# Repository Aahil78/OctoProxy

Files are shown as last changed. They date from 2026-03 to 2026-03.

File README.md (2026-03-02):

# OctoProxy

OctoProxy is a raspberry pi based OctoPrint server for the Bambu Lab A1, it acts as a proxy for region locked and LAN Only mode printers to have remote monitoring and access. It also has a Tailscale VPN server to trick Bambu Studio to think you are on  your LAN when you arent, this will allow you to send prints from Bambu Studio to any LAN Only printer from anywhere in the world. You can also use it as a printago fuse or simplyprint server.

Features:
  - Runs OctoPrint allowing you to send prints from anywhere.
  - Uses a Raspberry Pi 4 as the SBC, allowing for upgrades like sensors, lights, software upgrades, and more.
  - WS2812B/SK6812 3 Pin connector for custom lights.
  - Has a CSI Camera, allowing better timelapses and better video streaming footage. We all know the A1 Camera is..... special.
  - GPIO Pins broken out for upgrades.

## Images

### PCB:



### Case:





(Top has magnets embedded)

### Schematic:



## BOM:

| Item: | Quantity: | Price: | Link: | Total Cost: |
|---|---|---|---|---|
| Raspberry Pi 4 (Already have it) | 1 | $0 | N/A | |
| Raspberry Pi 4 Camera | 1 | $23.08 | Camera | |
| PCB | 1 | $15.78 | | |
| Raspberry Pi Fan | 1 | $4.35  | Fan | |
| Standoffs & Screws | 1 kit | $10 | Screws and standoffs | |
| 3 Pin Female Header | 3 | $2.50  | 3 Pin Header | |
| 4 Pin Female Header | 2 | $2.72  | 4 Pin Header | |
| 7 Pin Female Header | 1 | $3.10  | 7 Pin Header | |
| 6 Pin Female Header | 2 | $2.95  | 6 Pin Header | |
| 2 Pin Male Header | 1 | $1.00  | 2 Pin Header | |
| 1 Pin Header | 1 | $1 | 1 Pin Header | |
| 330ohm Resistor | 1 | $1.47  | Resistor | |
| 40Pin SMT Connector | 1 | $4.77  | SMT Connector | |
| WS2812B LED Strip | 1 | $6.46  | LED Strip | |
| | | | | 79.18 (Will pay extra myself) |

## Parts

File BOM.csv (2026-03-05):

Item: | Quantity: | Price: | Link: | Total Cost:
Raspberry Pi 4 (Already have it) | 1 | $0 | N/A
Raspberry Pi 4 Camera | 1 | $23.08 | https://a.aliexpress.com/_c3WMvg8r
PCB | 1 | $15.78 (Buying myself)
Raspberry Pi Fan | 1 | $4.35 | https://a.aliexpress.com/_c4KBPFfh
Standoffs & Screws | 1 kit | $10 | https://a.aliexpress.com/_c3n6VUOF
3 Pin Female Header | 3 | $2.50 | 3https://a.aliexpress.com/_c3jsRT47
4 Pin Female Header | 2 | $2.72 | https://a.aliexpress.com/_c3jsRT47
7 Pin Female Header | 1 | $3.10 | https://a.aliexpress.com/_c3jsRT47
6 Pin Female Header | 2 | $2.95 | https://a.aliexpress.com/_c3jsRT47
2 Pin Male Header | 1 | $1.00 | https://a.aliexpress.com/_c3YBvwLN
1 Pin Header | 1 | $1 | https://a.aliexpress.com/_c3YBvwLN
330ohm Resistor | 1 | $1.47 | https://a.aliexpress.com/_c44BS1eP
40Pin SMT Connector | 1 | $4.77 | https://a.aliexpress.com/_c3YsGuH1
WS2812B LED Strip | 1 | $6.46 | https://a.aliexpress.com/_c3SKBgij
3.5inch DSI LCD | 1 | $30.94 | https://a.aliexpress.com/_c3eojfjv
 |  |  |  | $93.98 (Will pay extra myself)

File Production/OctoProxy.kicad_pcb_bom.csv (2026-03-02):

Designator | Quantity | Value | Footprint | Package | MPN | DNP | Mount_Type | Description
J1 | 1 | GPIO | Raspberry_Pi_Shield_Bottom_Entry_No_Mounting_Holes |  |  |  | tht
J10, J3 | 2 | Conn_01x04_Pin | Harwin_M20-89004xx_1x04_P2.54mm_Horizontal |  |  |  | smt
J11, J2, J6 | 3 | Conn_01x03_Pin | Harwin_M20-89003xx_1x03_P2.54mm_Horizontal |  |  |  | smt
J4 | 1 | Conn_01x07_Pin | Harwin_M20-89007xx_1x07_P2.54mm_Horizontal |  |  |  | smt
J5 | 1 | Conn_01x02_Pin | PinHeader_1x02_P2.54mm_Horizontal |  |  |  | tht | Generic connector, single row, 01x02, script generated
J7, J8 | 2 | Conn_01x06_Pin | Harwin_M20-89006xx_1x06_P2.54mm_Horizontal |  |  |  | smt
J9 | 1 | Conn_01x01_Pin | PinHeader_1x01_P2.54mm_Horizontal |  |  |  | tht | Generic connector, single row, 01x01, script generated
R3 | 1 | 330ohm | R_Axial_DIN0207_L6.3mm_D2.5mm_P10.16mm_Horizontal |  |  |  | tht | 330Ω, 1/4W Resistor

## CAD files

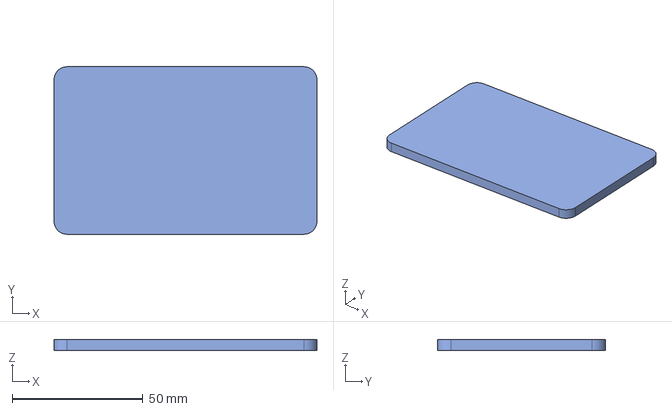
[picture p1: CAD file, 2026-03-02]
CAD/Top.step
100.6 x 64.1 x 4.20 mm

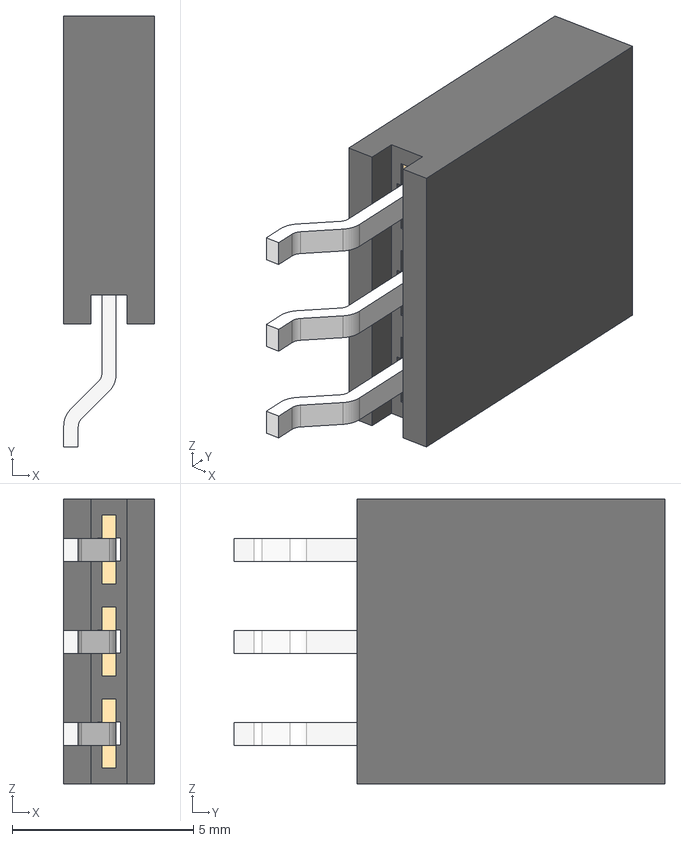
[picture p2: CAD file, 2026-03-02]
src/3D Models/3pin-right-angled-2.54mm.stp
2.50 x 11.9 x 7.87 mm

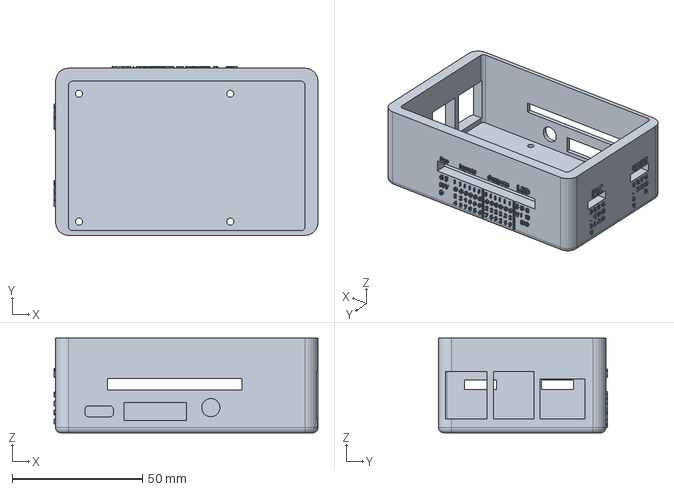
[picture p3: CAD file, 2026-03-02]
CAD/Base.step
101.2 x 64.7 x 36.3 mm

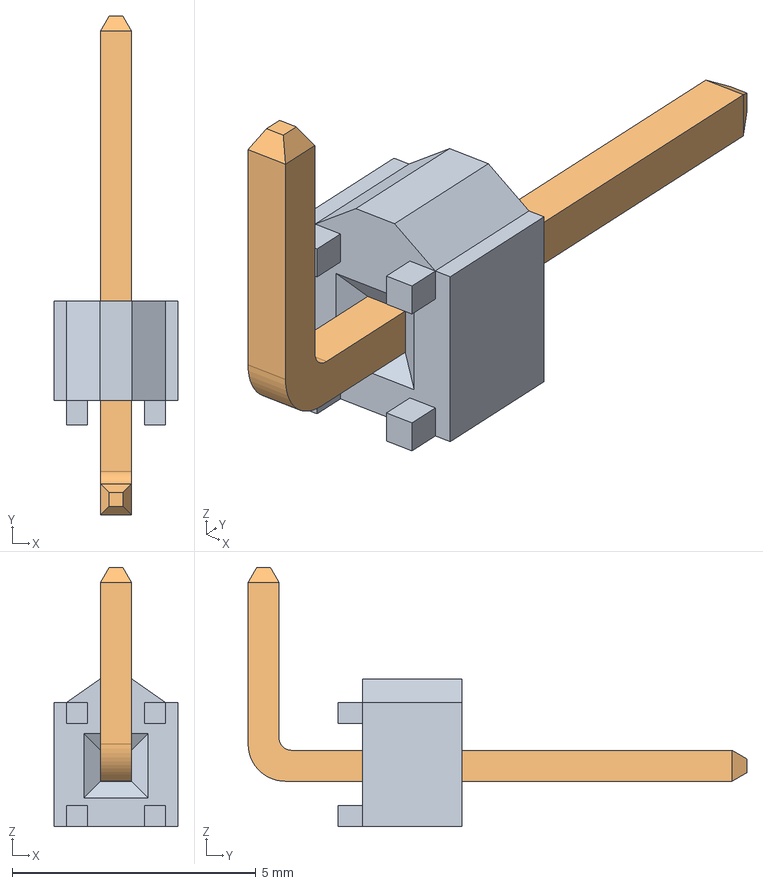
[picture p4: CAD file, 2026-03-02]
src/3D Models/TSW-101-08-T-S-RA.stp
2.54 x 10.2 x 5.31 mm
TSW-101-08-T-S-RA_body
T-1S6-08-TSW-1-08-1-RA-S

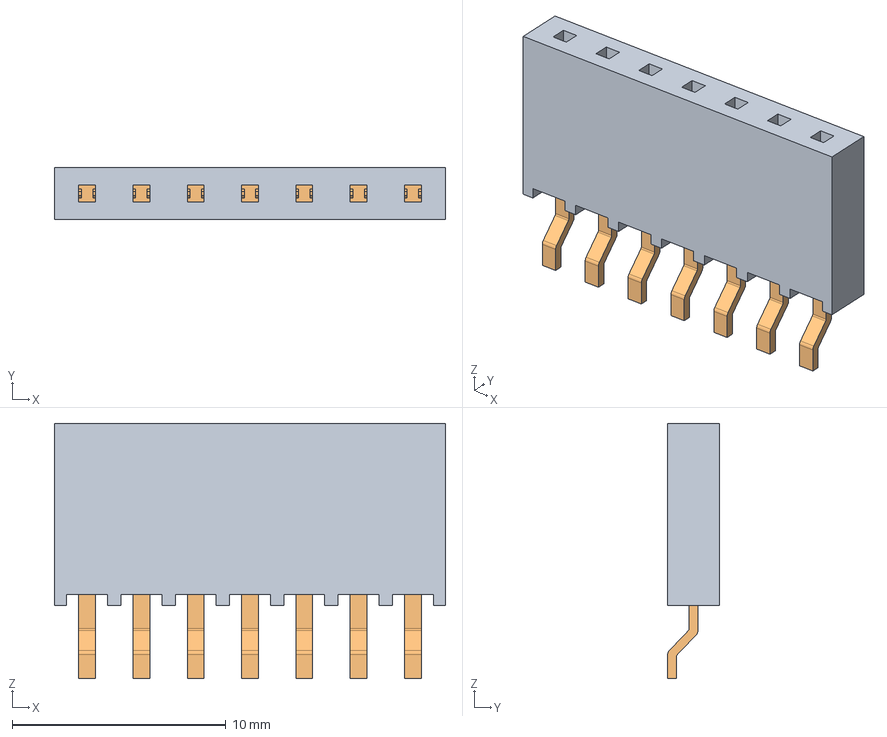
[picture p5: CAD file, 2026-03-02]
src/3D Models/7pin-2.54mm-right-angled.stp
18.3 x 2.41 x 11.9 mm
SMH-107-S_socket
C-08-03-07-S_SMH

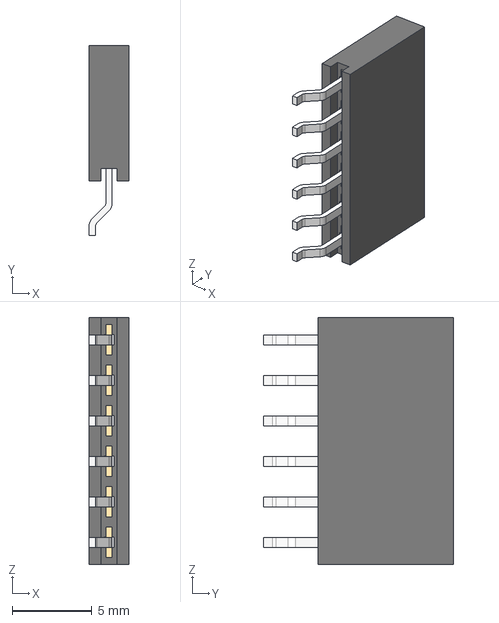
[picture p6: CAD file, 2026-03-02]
src/3D Models/6pin-right-angled-2.54mm.stp
2.50 x 11.9 x 15.5 mm

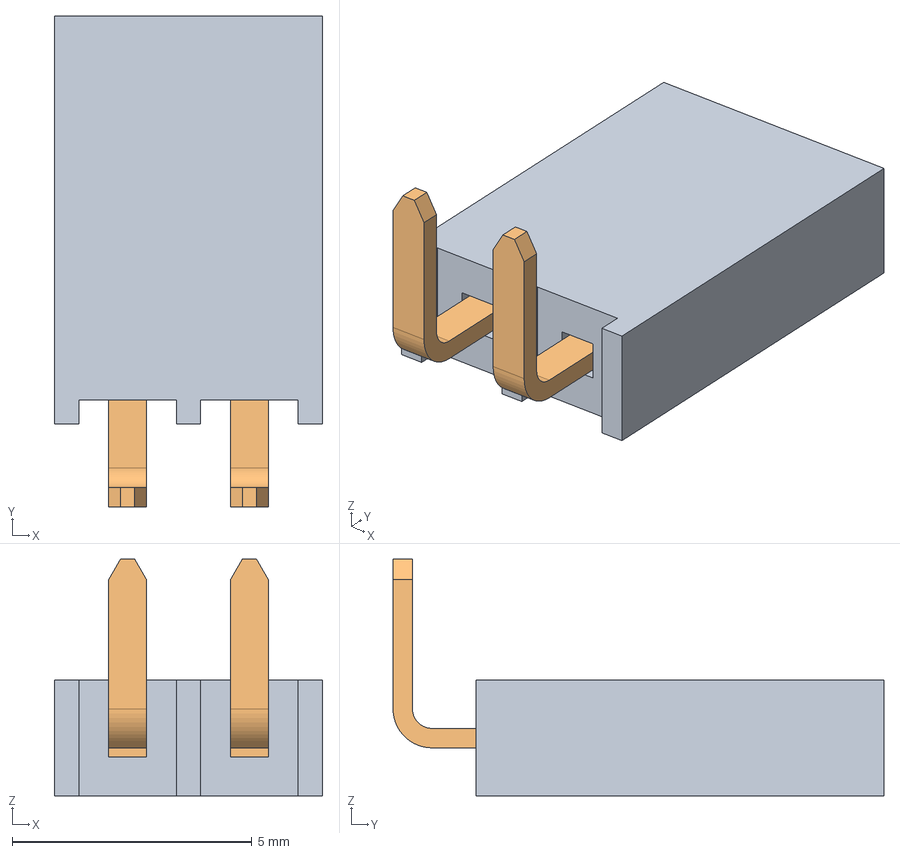
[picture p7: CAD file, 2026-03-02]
src/3D Models/2pin-right-angled-connector-2.54mm.stp
5.59 x 10.2 x 4.94 mm
T1SSW-102-02-L-S-RA
P2SSW-102-02-L-S-RA

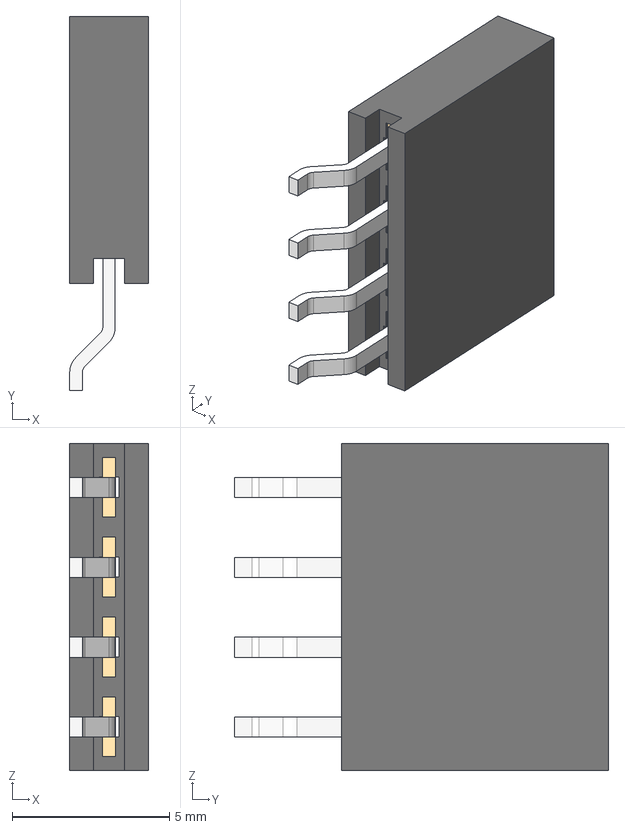
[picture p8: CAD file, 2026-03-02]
src/3D Models/4pin-female-2.54mm-rght-angled.stp
2.50 x 11.9 x 10.4 mm

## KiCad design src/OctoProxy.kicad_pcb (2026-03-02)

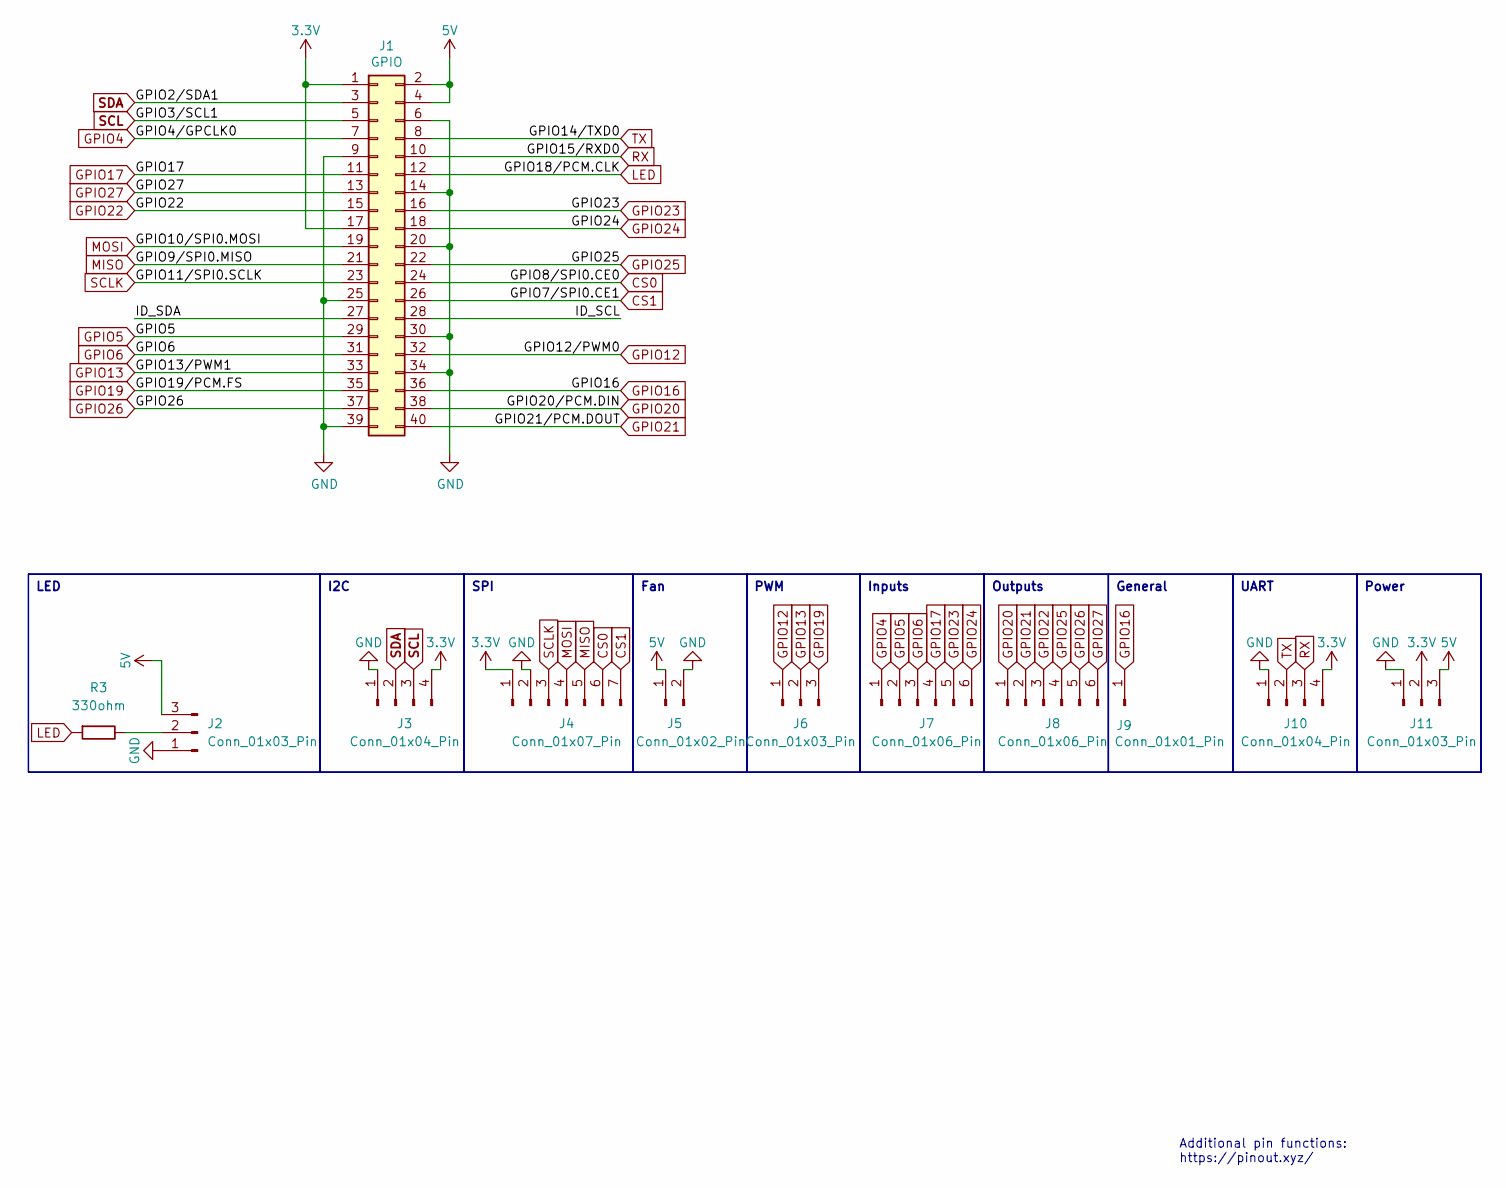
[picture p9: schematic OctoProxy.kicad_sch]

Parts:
J1: GPIO; Raspberry_Pi_Shield_Bottom_Entry_No_Mounting_Holes
J2, J6, J11: Conn_01x03_Pin; Harwin_M20-89003xx_1x03_P2.54mm_Horizontal
J3, J10: Conn_01x04_Pin; Harwin_M20-89004xx_1x04_P2.54mm_Horizontal
J4: Conn_01x07_Pin; Harwin_M20-89007xx_1x07_P2.54mm_Horizontal
J5: Conn_01x02_Pin; PinHeader_1x02_P2.54mm_Horizontal
J7, J8: Conn_01x06_Pin; Harwin_M20-89006xx_1x06_P2.54mm_Horizontal
J9: Conn_01x01_Pin; PinHeader_1x01_P2.54mm_Horizontal
R3: 330ohm; R_Axial_DIN0207_L6.3mm_D2.5mm_P10.16mm_Horizontal

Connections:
3.3V: J1.1, J1.17, J3.4, J4.1, J10.4, J11.2
5V: J1.2, J1.4, J2.3, J5.1, J11.3
/ID_SCL: J1.28
/ID_SDA: J1.27
CS0: J1.24, J4.6
CS1: J1.26, J4.7
GND: J1.6, J1.9, J1.14, J1.20, J1.25, J1.30, J1.34, J1.39, J2.1, J3.1, J4.2, J5.2, J10.1, J11.1
GPIO4: J1.7, J7.1
GPIO5: J1.29, J7.2
GPIO6: J1.31, J7.3
GPIO12: J1.32, J6.1
GPIO13: J1.33, J6.2
GPIO16: J1.36, J9.1
GPIO17: J1.11, J7.4
GPIO19: J1.35, J6.3
GPIO20: J1.38, J8.1
GPIO21: J1.40, J8.2
GPIO22: J1.15, J8.3
GPIO23: J1.16, J7.5
GPIO24: J1.18, J7.6
GPIO25: J1.22, J8.4
GPIO26: J1.37, J8.5
GPIO27: J1.13, J8.6
LED: J1.12, R3.1
MISO: J1.21, J4.5
MOSI: J1.19, J4.4
unnamed: J2.2, R3.2
RX: J1.10, J10.3
SCL: J1.5, J3.3
SCLK: J1.23, J4.3
SDA: J1.3, J3.2
TX: J1.8, J10.2

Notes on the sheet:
Additional pin functions: https://pinout.xyz/
Outputs
UART
LED
Power
I2C
SPI
PWM
Inputs
Fan
General

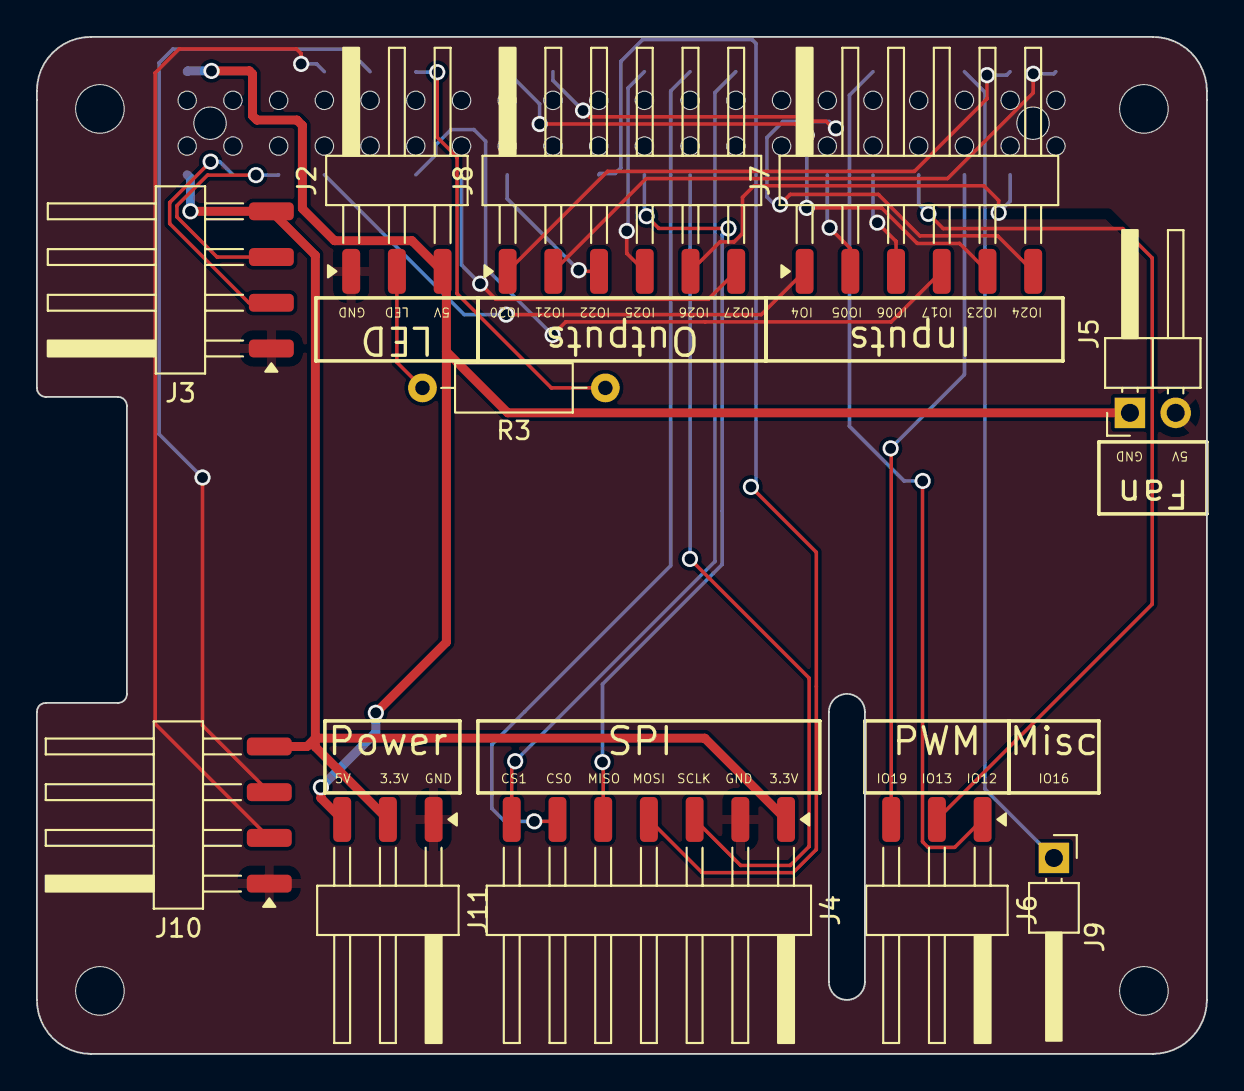
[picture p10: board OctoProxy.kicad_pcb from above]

Board: 2 copper layers, 65.0 x 56.5 mm, 16 parts (0 on the bottom side), 30 nets.

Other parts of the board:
MH1, MH2, MH3, MH4: MountingHole_2.7mm_M2.5

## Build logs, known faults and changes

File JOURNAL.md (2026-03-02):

# February 26th, 05:20pm : Brainstormed the idea and made the schematic

Hi! I recently got a Bambu Lab A1 from [Construct](https://construct.hackclub.com) (An event where you do 40hrs of 3D CAD to get an A1 Mini, do 70hrs and get an A1!! Ages 13-18) but it was region locked as only the A1 CN Version was available over here. So I thought, why not make an upgrade for my printer? So I brainstormed this project. 

---
Features:
  - Runs OctoPrint allowing you to send prints from anywhere.
  - Uses a Raspberry Pi 4 as the SBC, allowing for upgrades like sensors, lights, software upgrades, and more.
  - WS2812B/SK6812 3 Pin connector for custom lights.
  - Has a CSI Camera, allowing better timelapses and better video streaming footage. We all know the A1 Camera is..... special.
  - GPIO Pins broken out for upgrades.
  - Uses a DSI Touchscreen for print stats/different control panel.
---
So after thinking abt all of this, I created a schematic in KiCad with the following broken out: 
  - ARGB LED Strip 3pin connector (330ohm on Data line - Data Line tied to GPIO18)
  - I2C Breakout
  - SPI Breakout
  - Fan Breakout (2pins to 5v and GND)
  - PWM Pins GPIO12, 13, and 19
  - Input Pins GPIO4, 5, 6, 17, 23, and 24
  - Output Pins GPIO20, 21, 22, 25, 26, and 27
  - General Pin Broken Out GPIO16
  - UART Pins - TX, RX, 3.3v, and GND.
  - Power Pins - GND, 3.3v, and 5v

I'll make a PCB now then work on the enclosure.




**Total time spent: 3h**

# February 26th, 06:18pm : Changed the schematic

Okay so I was assigning footprints and found out I don't have a footprint for the Pi HAT with cutouts for DSI and CSI cables, so i made a new project with the "Raspberry Pi HAT" Template on KiCad and copy pasted everything then put all the Net Labels to the correct pins.



**Total time spent: 58mins**

# Fubruary 26th, 08:00pm : Made the PCB

Soooo, I made the PCB!!! It was pretty hard to arrange all the components in a limited space, now I'm gonna work on the enclosure.



**Total time spent: 1hr 42mins**

# February 28th, 01:15am : Labled all pins

So I went over and exported the 3D Model of the PCB and noticed I didnt label any of the pins, so I did that rn. I didnt do the ones on the side cz theres no space and they may not be used that much, might label those on the enclosure if I can.



**Total time spent: 15mins**

# February 28th, 03:45am : Populated the PCB

Sooo I researched all the components, shortlisted them, decided the final components, downloaded it's 3D Model, imprt it, then position it onto my PCB in the assembly. Now I'll export the populated PCB+Raspberru Pi then make my sketch around that.



**Total time spent: 3hrs 30mins**

# March 1st, 10:47am : Redid the PCB

So last night in Onshape, I found out the GPIO Header was mislaigned, so I had to delete all traces, replace the footprint to spaarkfun's PCM RPi Hat connector, and precisely aligned everything asw. I then routed everything again, I also added all 3D Models to the PCB this time to save time for later on.







**Total Time Spent: 2hrs 45mins**

# March 2nd, 10:07pm : Starting the case

I added the PCB and Pi in OnShape, connected them im an assembly, exported the assembly, added the export back into OnShape as a part studio, then I started off the case, aligned the Pi in it, and made cutouts for the Type C, HDMI, and audio port.




**Total time spent: 3hrs**

# March 3rd, 12:27am : Case bottom done

I made the whole bottom, added text, cutouts, fillets, etc. I'll make the top now, might use heatset inserts to screw in the top. (The top is really big cz I have to fit in a 2010 or 4010 fan too.)



**Total time spent: 2hr 20mins**

# March 3rd, 01:17am : Finished the case!

So im finally done with the case!! I'll use a different fan that screws onto the pi not case. and for the camera I'll use a stand I have at home, also for the LCD, I am not gonna add one because this is intended for a server, but if needed i can use the HDMI ports. I'll add all files then submit.



**Total time spent: 1hr**

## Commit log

2026-02-26 Add JOURNAL,md
    Documented brainstorming and schematic creation for OctoProxy.
2026-02-26 Add journal entry for PCB creation
    Documented the creation of the PCB and time spent.
2026-02-27 Document pin labeling on PCB
    Labeled all pins on the PCB and noted labeling limitations.
2026-02-27 Revise timestamps and add new journal entries
    Corrected timestamp formatting and added new journal entries detailing the labeling of pins and component population on the PCB.
2026-03-02 Update JOURNAL.md with March 3rd entry
    Added journal entry for March 3rd detailing progress on case bottom.
2026-03-05 Update and rename BOM - Sheet1.csv to BOM.csv
    [BOM - Sheet1.csv, BOM.csv]
2026-03-05 Fix BOM.csv formatting and update item details
    [BOM.csv]

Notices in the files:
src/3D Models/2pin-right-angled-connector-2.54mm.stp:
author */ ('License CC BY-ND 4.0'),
